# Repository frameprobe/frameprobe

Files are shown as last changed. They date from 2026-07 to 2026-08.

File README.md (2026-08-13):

# frameprobe

End-to-end display latency measurement: the time from a mouse input (click or
movement) to a visible change on screen, measured with a photodiode strapped to
the monitor.

**How it works:**

- An RP2040 sends a USB HID mouse click (or, in move mode, a mouse movement)
- The input causes a brightness change on the monitor under test (any application works, as long as the brightness difference is big enough)
- The photodiode picks up the change
- The RP2040 streams ADC samples over serial
- The host logs them to CSV
- `analyze.py` computes the latency

## Components

| Component | Path | Description |
|---|---|---|
| Hardware | `hardware/` | KiCad 10 PCB source (`hardware/pcb/`) and 3D-printable enclosure for the sensor (VBPW34S photodiode + TLV9061 transimpedance amplifier). |
| Firmware | `arduino/` | Runs on any RP2040 board. Fires the mouse input (click, or a single 16-bit HID move report in move mode), samples the photodiode on A1 (14-bit ADC, 12,000 samples per run), sends results as CSV lines over serial. |
| Host software | `main.py` | Interactive serial terminal. Starts/stops test runs, configures measurement mode, click count and interval, logs device data to `output/*.csv`. |
| Analyzer | `analyze.py` | Computes latency from session CSVs or whole folders. Reports signal/noise separation, mean ± 95% CI, sd, median, p5, p95, spread, min, max and an ASCII histogram. Every field is explained in [analyze.md](./analyze.md). |
| Chart data | `analyze_all.py` | Pools each direct subfolder of a results folder and prints chart-ready JSON (medians with error bars, plus shared-bin histograms) for comparing test cases. |
| Reference data | `test_run1/` | Captures and notes from an X11-vs-Wayland test matrix on a 500 Hz QD-OLED (`test_setup.md`, `test_matrix.md`). Done with Perfboard-era sensor, use `-t 100` to reproduce the published numbers. |

## Images

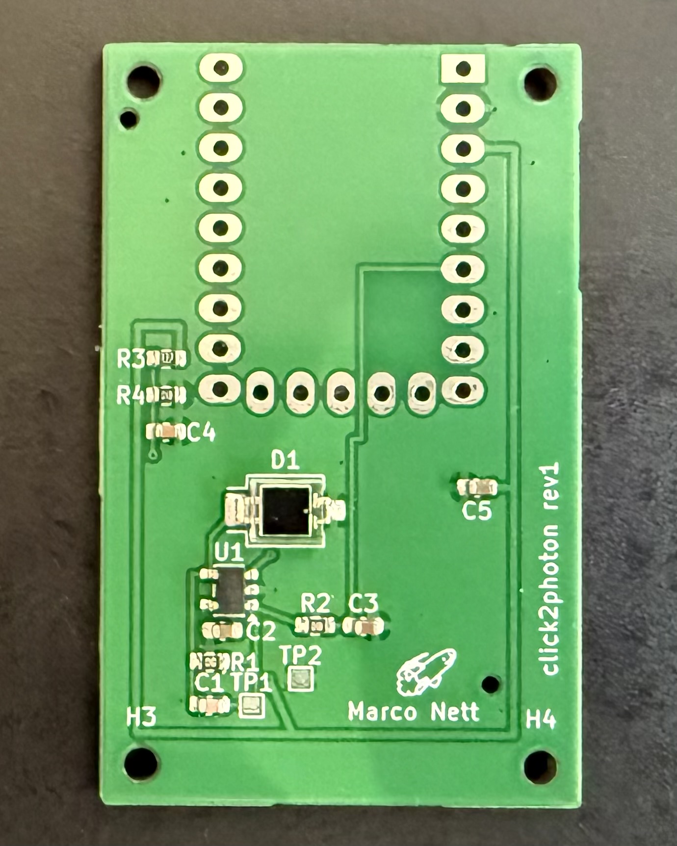
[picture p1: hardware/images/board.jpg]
Board
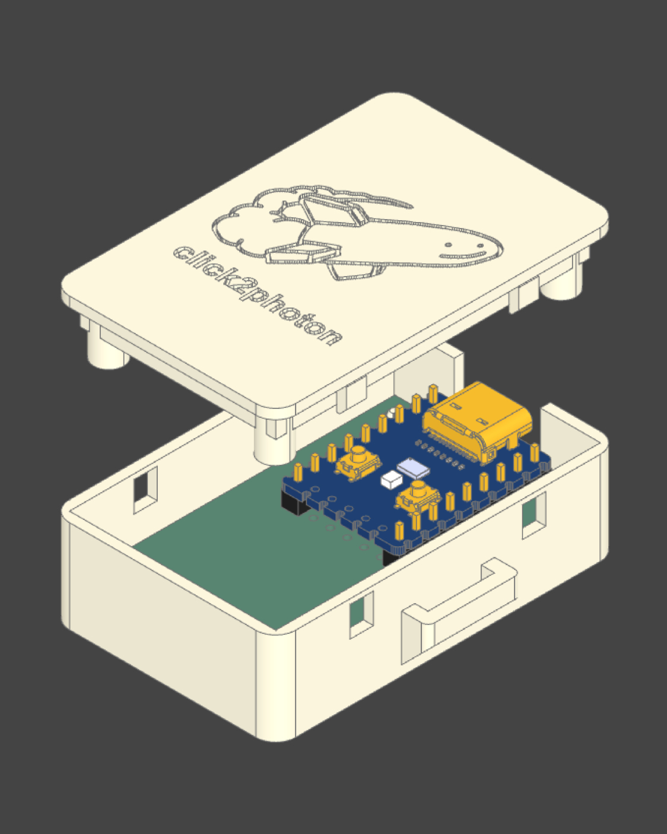
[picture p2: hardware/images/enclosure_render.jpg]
Enclosure Render
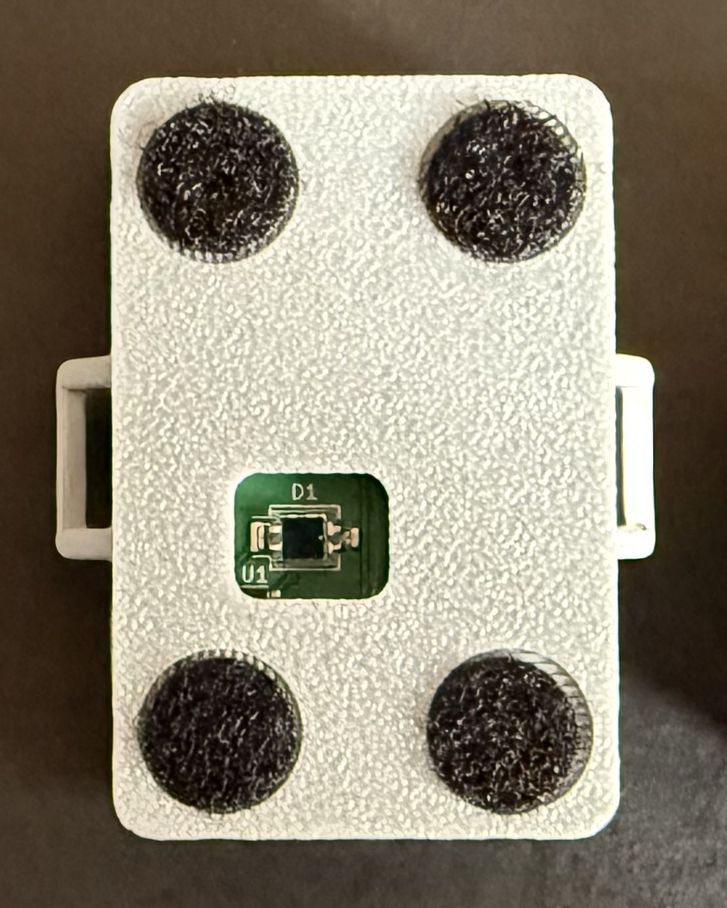
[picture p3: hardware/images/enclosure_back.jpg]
Enclosure Back
  

## Host software CLI (`main.py`)

Auto-detects the device by USB VID/PID and provides an interactive prompt. Pass a port
as the first argument to override the search (`uv run main.py /dev/ttyACM1`).

| Command | Description |
|---|---|
| `start` | Start a test session (3s countdown). Logs to `output/<timestamp>_session.csv`. |
| `stop` | Stop the test and close the session CSV. |
| `debug`, `d` | Enable debug mode: device streams raw ADC readings and voltage. |
| `interval <float>`, `i <float>` | Set the time between measurements in seconds (default 0.5). |
| `clicks <int>`, `c <int>` | Set the number of measurements per session (default 10). |
| `mode <click\|move>`, `m <...>` | Set the measurement mode (default `click`). |
| `distance <1-32767>`, `x <int>` | Move mode: distance in HID counts, sent as one atomic report (default 500). |
| `direction <up\|down\|left\|right>`, `r <...>` | Move mode: direction (default `right`). |
| `test`, `t` | Move mode: Fire one visible move with the current settings, then move back after 1s. |
| `connect` / `disconnect` | Open / close the serial connection. |
| `help` | Show the command list. |
| `exit`, `quit` | Disconnect and quit. |

## Measurement modes

- **Click** (default): each measurement is a left mouse click, e.g. a muzzle
  flash in a game, or an app that toggles the screen color on click.
- **Move**: each measurement is a single mouse movement, e.g. camera turns in
  a game. After each measurement the firmware moves the cursor back to where it started.

## Usage

`main.py` and `analyze.py` run on macOS, Linux and Windows.

Before starting a session, run an application on the PC under test in
which the mouse input causes a sufficiently large brightness change.

```sh
uv sync                     # set up Python environment
uv run main.py              # connect to the device, then type: start
uv run main.py COM5         # might be needed in Windows if COM port auto-detect fails
uv run analyze.py output/<session>.csv
uv run analyze.py output/   # or pool a whole folder of sessions
```

By default, `analyze.py` automatically calibrates based on the given input files.

## Test run

`test_run1/` contains methodology and results of the testing I did for a blog post: [Measuring input latency on Linux: X11 vs Wayland, VRR, and DXVK](https://marco-nett.de/blog/measuring-input-latency-on-linux-x11-vs-wayland-vrr-dxvk/).

This test run was done with a proof-of-concept design of the PCB with less sensitivity. To replicate the results from the blog post exactly, use the analyzer with its historical threshold of 100, for example: `uv run analyze.py test_run1/output/1_x11_ll-ON_vrr-ON -t 100`.

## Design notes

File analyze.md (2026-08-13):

# analyze.py output explained

Each value describes the click-to-photon latencies of one file or one pooled folder (all clicks from all its CSV files together).

For each click, the latency is the moment the light level crosses the midpoint (50%) of that click's own dark↔light swing and stays past it for 5 samples (timestamped at the first) — both reference levels are medians measured from the click's samples, so no per-hardware threshold tuning is needed. The same swing also yields two supplementary timestamps per click, t10 (onset) and t90 (near-settled). All headline stats come from the 50% crossing (t50). Passing `-t` instead uses the legacy fixed-delta detection (first single sample more than the given ADC delta away from the mean baseline), which reproduces the originally published numbers exactly.

- **mode** — which input event the sessions measured: *click* or *move* (read from the metadata comment line newer captures carry). Only shown when at least one file has metadata; files recorded before the metadata line existed are listed as *unknown*, so a pooled folder that mixes tagged and untagged sessions says so instead of claiming a single mode.

- **reference** — only shown with `--from-delivery`: latencies count from the moment the USB host actually picked the click report up off the device, not from the firmware pressing the button. A mouse only hands its click to the PC when the PC polls for it (every 1 ms here), so the default numbers include a random 0–1 ms wait — that's real button-to-photon latency, what a person feels. `--from-delivery` removes exactly that wait (newer captures record it per click), giving a tighter number that isolates the PC + display pipeline — better for A/B-ing displays, but ~0.5 ms lower than what a user experiences. Only captures that recorded the delivery moment can be re-referenced; older files are skipped as *no-delivery*.

- **detection** — how latencies were timed. In automatic mode it also reports the signal/noise separation: each click's swing divided by the peak-to-peak noise of its pre-click window. The minimum is the worst click in the set — if it drops toward ~2×, the sensor is barely seeing the transition (reposition it).

- **measurements** — number of clicks with a detected screen change. *skipped* = clicks with no valid transition, broken down by reason: *no-transition* (missed click, slipped sensor — swing within noise), *incomplete* (change still in progress at capture end), *malformed* (unparseable row), *no-delivery* (the host never picked the click up — device unplugged or host suspended mid-run; or, under `--from-delivery`, a file too old to record delivery); they are excluded from all stats.

- **flicker** — only shown when some clicks were measured through temporal light modulation (TLM). TLM is the umbrella term for any periodic brightness variation of the display: a PWM-strobed backlight (e.g. MacBook Pro mini-LED, ~3 kHz) and a deep OLED per-refresh brightness dip (e.g. QD-OLED at its refresh rate) look identical to the photodiode, so the analyzer names what it measures rather than guessing the cause — the reported frequency tells you which it is (kHz range → likely backlight PWM, ≈ the refresh rate → refresh flicker). Modulation that reaches past the midpoint of the swing corrupts normal crossing detection, so every click is checked before detection: when a reference window oscillates strongly periodically and the oscillation reaches past the midpoint, detection runs on a moving average of exactly one modulation period, which cancels the modulation — so those clicks are measured the same way regardless of direction. The line reports how many clicks this applied to and the modulation frequency. Timing is blurred by at most one modulation period, and the separation figures for these clicks describe the filtered signal. Mild flicker that stays below the midpoint does not trigger this and keeps raw detection.

- **delivery** — only shown for captures that record it: how long each click sat on the device before the host's USB poll picked it up (median, min, max). Expect a median around 0.5 ms spread across 0–1 ms — the physics of 1000 Hz polling. It is a diagnostic, always relative to the press regardless of `--from-delivery`: values hugging 1 ms or beyond suggest the host was polling slowly or the bus was busy. This is exactly the component `--from-delivery` subtracts.

- **mean ± … (95% CI)** — average latency. The ± is the uncertainty of that average: rerunning the same test would land the mean inside this range 95% of the time. Two cases whose ranges don't overlap are genuinely different. For folders, the margin is widened if the individual sessions disagree with each other.

- **median** — the middle click: half were faster, half slower. Like the mean but immune to a few extreme values.

- **p5** — the fast tail: 5% of clicks were faster than this. Approximates the best-case pipeline latency (click landed at the luckiest moment of the refresh cycle). A robust version of *min*.

- **p95** — the slow tail: 5% of clicks were slower than this. The "feels laggy" number — worst cases players actually notice. Where frame-pacing features should show their effect.

- **spread (p95 − p5)** — consistency: how wide the typical latency range is. Smaller = more predictable feel. More meaningful than sd, which is inflated the same way everywhere.

- **min / max** — single fastest and slowest click. Sanity checks only; each is one sample, so don't base conclusions on them.

- **onset (t10)** — median time to 10% of the swing: the earliest defensible "light started changing" moment, closest to a first-photon latency. Only counted for clicks where 10% of the swing clears the pre-click peak-to-peak noise — on a flickering white QD-OLED baseline that level is inside the flicker, so those clicks report t50 but no t10 (the report says how many). Absolute onset numbers are noise-floor dependent; use t50 for comparisons.

- **response (t10→t90)** — median time from 10% to 90% of the swing: how long the measured transition itself takes. This is sensor + panel combined — on the slow perfboard sensor it is dominated by the amplifier, on the fab PCB it approaches the panel's true response — so it is comparable within one sensor generation only.

- **histogram** — latency distribution in 0.5 ms bins; each row shows a bin's count as a bar. Shows the shape a single number can't: whether the whole block shifts between cases, whether a case has a longer tail, or whether clicks clump at multiples of the 2 ms frame period.

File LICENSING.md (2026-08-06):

# Licensing

Copyright (C) 2026 Marco Nett.

| Path | Licence |
|---|---|
| `hardware/` — PCB source, enclosure | CERN-OHL-S v2, strongly reciprocal ([`hardware/LICENSE`](hardware/LICENSE)) |
| `arduino/`, `main.py`, `analyze*.py`, `*.sh` | GPL-3.0-or-later ([`LICENSE`](LICENSE)) |

## Name and logo

**All rights to the frameprobe name and the rocket logo are reserved.**
Neither licence grants trademark or design rights. This covers the logo
wherever it appears: the PCB silkscreen and gerbers, the enclosure STLs, and
the renders and photos. Remove both before fabricating a modified board or
enclosure, and use your own branding. CERN-OHL-S counts trademark notices as
*Notices* (§1.10) and requires they be retained (§3.3), so this reservation
carries into derivatives.

## Third-party material

Not my work, not covered by the licences above, and under their authors' own
terms. Both are cosmetic, 3D preview and STEP/STL export only, not the
electrical design or the fab outputs:

- `hardware/pcb/3dmodels/RP2040-Zero.step`: Waveshare RP2040-Zero model, STEP
  header credits `xiaojisheng`
- `hardware/pcb/3dmodels/LED_VBPW34S_VIS.step`: Vishay

The design also uses KiCad's standard footprint libraries, whose CC-BY-SA-4.0
licence has an exception allowing this without the design becoming a derivative.
Build dependencies (arduino-pico, Adafruit NeoPixel, pyserial,
prompt_toolkit) are fetched, not redistributed here.

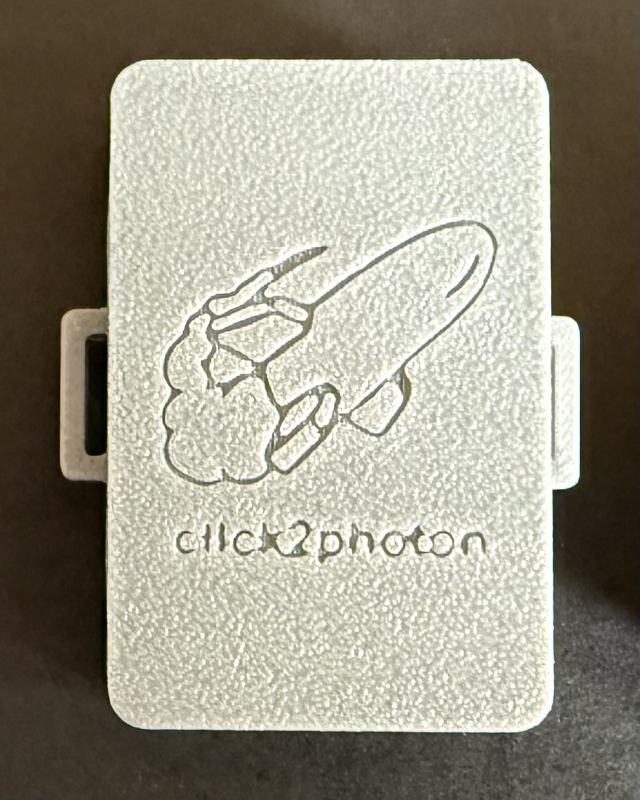
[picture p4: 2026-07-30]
hardware/images/enclosure_front.jpg

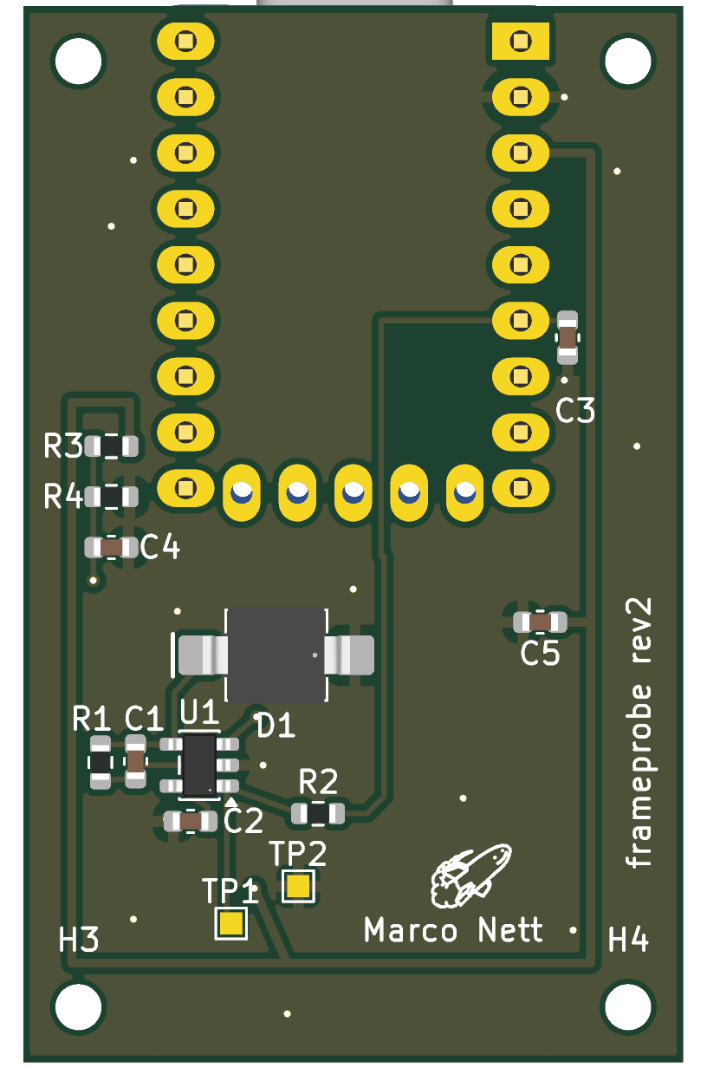
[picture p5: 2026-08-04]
hardware/pcb/render_top.png

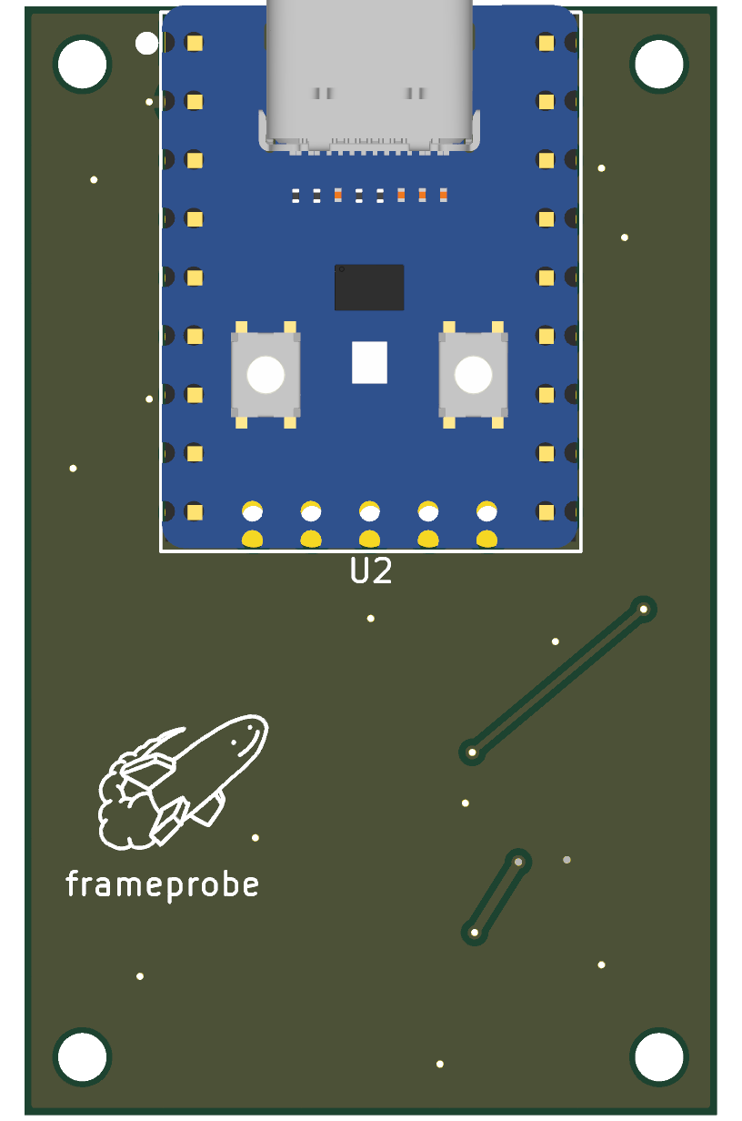
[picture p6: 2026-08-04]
hardware/pcb/render_back.png

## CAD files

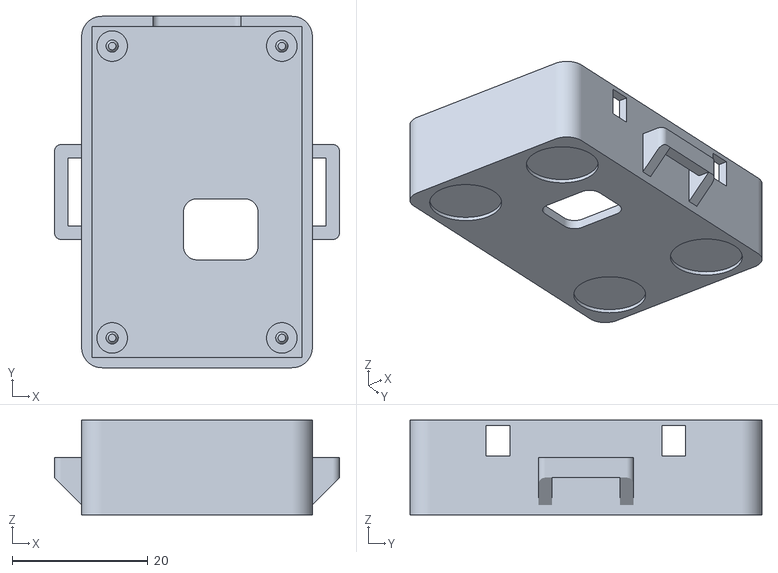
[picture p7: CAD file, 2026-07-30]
hardware/enclosure/case.stl
42.0 x 51.8 x 13.9

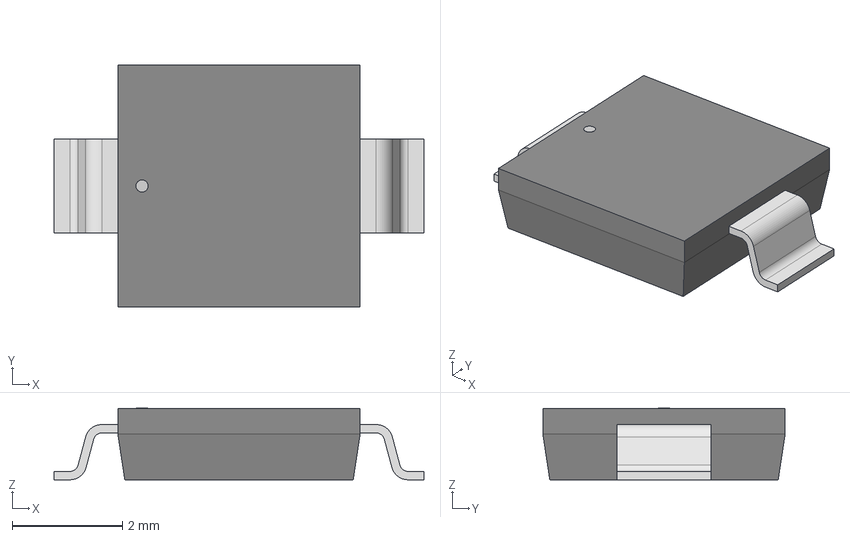
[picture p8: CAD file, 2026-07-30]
hardware/pcb/3dmodels/LED_VBPW34S_VIS.step
6.71 x 4.39 x 1.30 mm

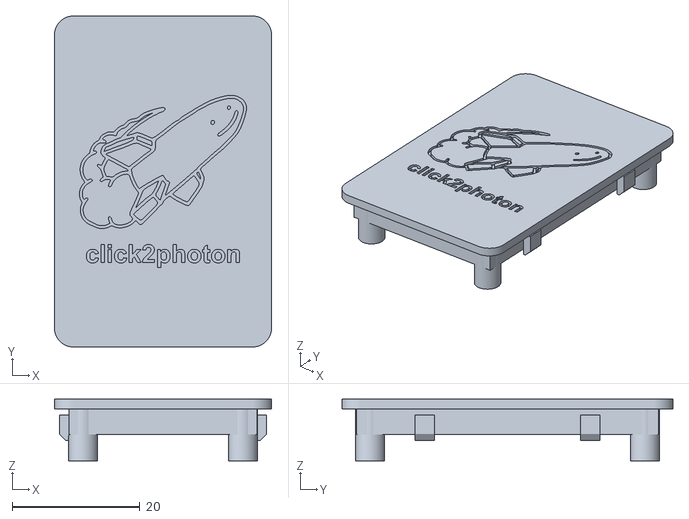
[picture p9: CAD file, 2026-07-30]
hardware/enclosure/lid.stl
34.0 x 51.8 x 9.65

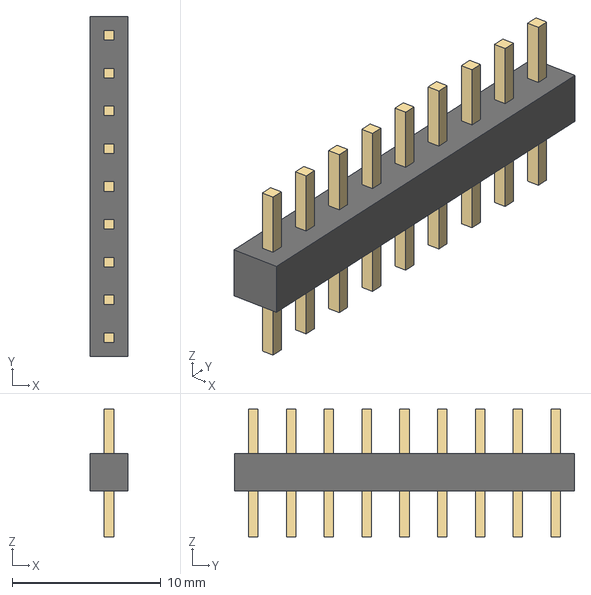
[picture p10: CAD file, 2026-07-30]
hardware/pcb/3dmodels/PinHeader_1x09_clipped.step
2.54 x 22.9 x 8.60 mm
insulator
pins

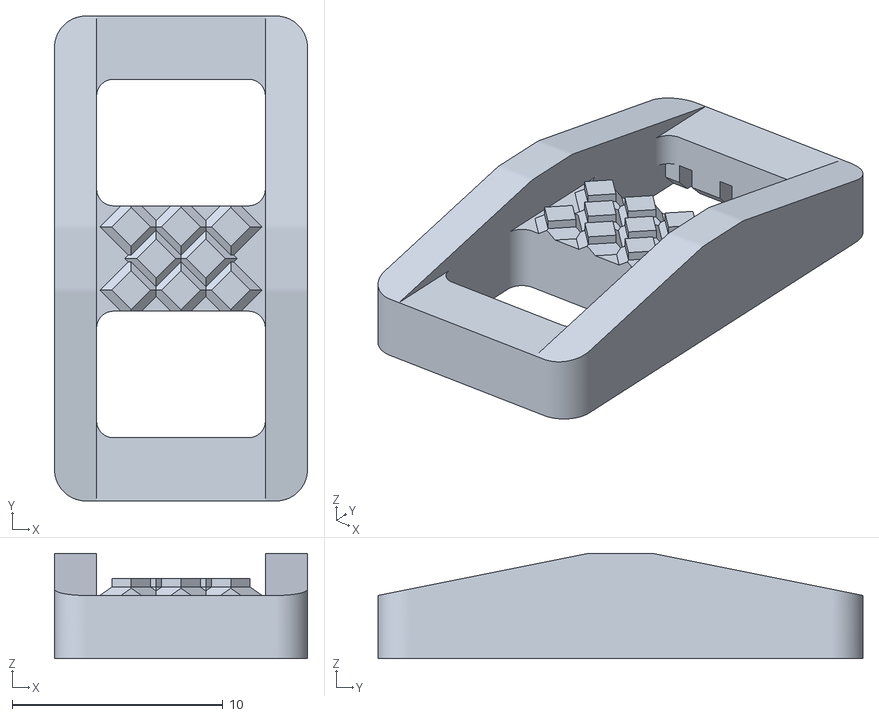
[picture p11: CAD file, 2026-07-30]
hardware/enclosure/strap_buckle.stl
12.0 x 23.0 x 5.00

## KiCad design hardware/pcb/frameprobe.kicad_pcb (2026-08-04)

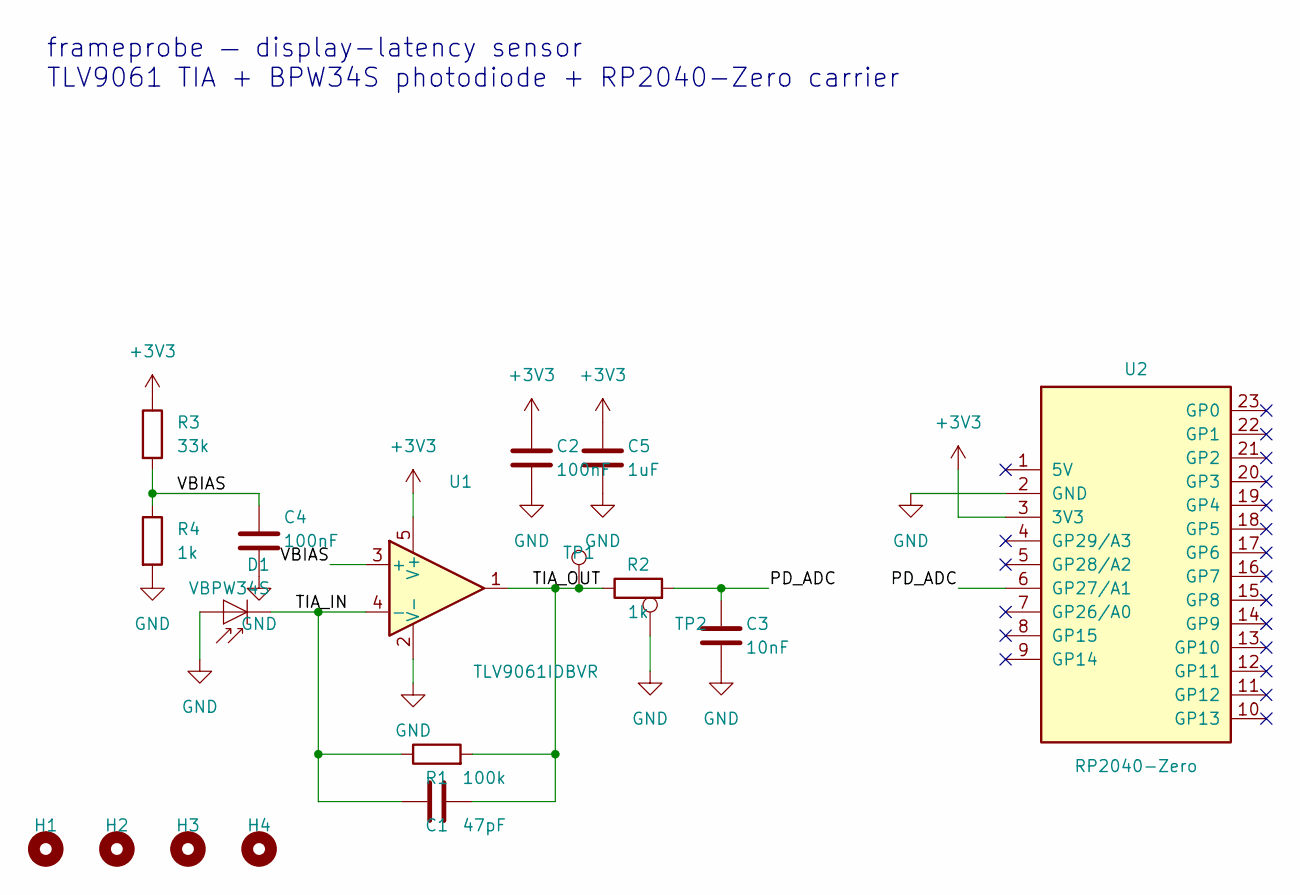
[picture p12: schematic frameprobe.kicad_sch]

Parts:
C1: 47pF; C_0603_1608Metric; LCSC C1671
C2, C4: 100nF; C_0603_1608Metric; LCSC C14663
C3: 10nF; C_0603_1608Metric; LCSC C57112
C5: 1uF; C_0603_1608Metric; LCSC C15849
D1: VBPW34S; LCSC C145262
H1, H2, H3, H4: MountingHole; MountingHole_2.1mm
R1: 100k; R_0603_1608Metric; LCSC C25803
R2, R4: 1k; R_0603_1608Metric; LCSC C21190
R3: 33k; R_0603_1608Metric; LCSC C4216
TP1: TIA_OUT; TestPoint_Pad_1.0x1.0mm
TP2: GND; TestPoint_Pad_1.0x1.0mm
U1: TLV9061IDBVR; SOT-23-5; LCSC C398358
U2: RP2040-Zero; RP2040-Zero_THT

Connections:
+3V3: C2.1, C5.1, R3.1, U1.5 (V+), U2.3 (3V3)
/PD_ADC: C3.1, R2.2, U2.6 (GP27/A1)
/TIA_IN: C1.1, D1.2 (K), R1.1, U1.4 (-)
/TIA_OUT: C1.2, R1.2, R2.1, TP1.1, U1.1
/VBIAS: C4.1, R3.2, R4.1, U1.3 (+)
GND: C2.2, C3.2, C4.2, C5.2, D1.1 (A), R4.2, TP2.1, U1.2 (V-), U2.2 (GND)

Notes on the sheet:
frameprobe — display-latency sensor TLV9061 TIA + BPW34S photodiode + RP2040-Zero carrier

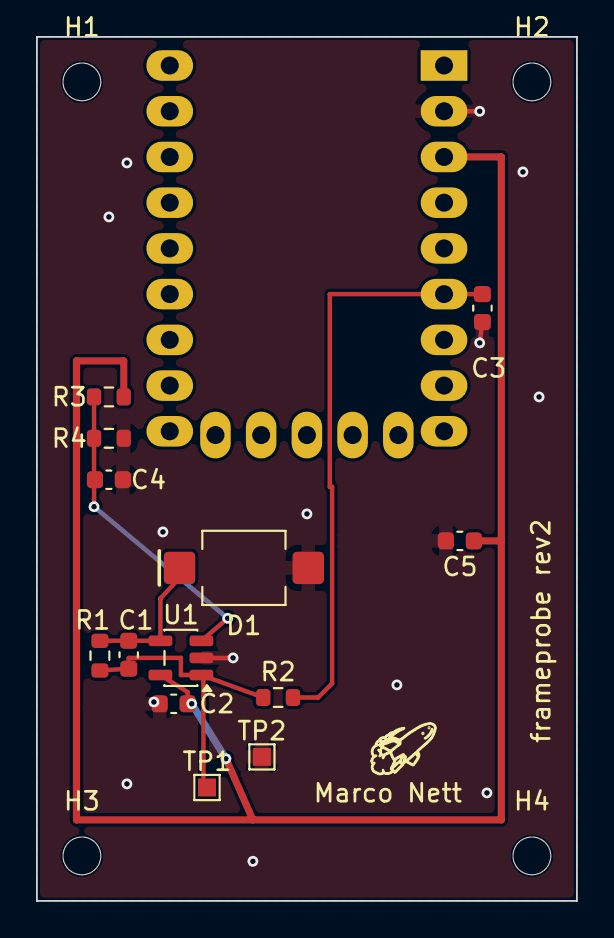
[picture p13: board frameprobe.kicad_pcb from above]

Board: 2 copper layers, 30.0 x 48.0 mm, 18 parts (1 on the bottom side), 6 nets.

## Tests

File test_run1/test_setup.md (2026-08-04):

# Test setup

## Hardware

- Mainboard: B450 GAMING PRO CARBON AC
- CPU: AMD Ryzen 7 5800X3D (16) @ 4.55 GHz
- GPU: NVIDIA GeForce RTX 4070 SUPER
- RAM: 2x8GB DDR4, 3200 MHz
- Monitor: MSI MAG 272QP QD-OLED X50 (500 Hz)
- Only one screen was connected to the system during the test

## Software

```sh
{
    echo "date: $(date -I)"
    echo "kernel: $(uname -r)"
    pacman -Q kwin
    pacman -Q xorg-server
    pacman -Q nvidia-utils
    pacman -Q proton-cachyos
    scxctl get
  } | tee versions.txt
```

Output:

```
date: 2026-07-12
kernel: 7.1.3-2-cachyos
kwin 6.7.2-1.1
xorg-server 21.1.24-1.1
nvidia-utils 610.43.03-1
proton-cachyos-native 1:11.0.20260602-3
no scx scheduler running
```

The test was done based on commit `7bc3f05` of frameprobe.

## System Settings

- 500 Hz
- Flip mode:
  - X11: On (via `nvidia-settings`)
  - Wayland: confirmed to be on (see below how)
- If VRR was tested:
  - X11: Enabled via `nvidia-settings` (changing this requires a reboot)
  - Wayland: Enabled via KDE Settings Menu (no reboot needed)
- `showcompositing` was off on Wayland (see [here](https://www.reddit.com/r/linux_gaming/comments/1u1z4qf/kde_kwin_patches_aiming_to_optimize_gaming/oqvlwdb/))

Flip mode (direct scanout) vs Blit mode (compositing) on Wayland: There is setting on Wayland, it decides itself if it composits a frame or uses direct scanout.\
To make sure the game is running in flip mode: Open "Kwin Debug Console" (it's a GUI tool) and in the "Effects" tab, enable `showcompositing`. Then make sure the game is fully focused and the only thing on screen in fullscreen mode. If there's no red border visible around the edged of the game, it's on Flip mode.

### dxvk

In all cases, the following is set in `dxvk.conf`:

```conf
d3d11.cachedDynamicResources = "c"
```

Depending on the test, an optimal `dxvk.conf` was setup:
- If VRR was off, `dxgi.maxFrameRate` was capped to 500 fps (the screens refresh rate)
- If VRR was on and `PROTON_DXVK_LOWLATENCY` was off, `dxgi.maxFrameRate` was capped to 497 fps (slightly below screen refresh rate)
- If VRR was on and `PROTON_DXVK_LOWLATENCY` was on, the following was used to utilize the low latency VRR frame pacing

```conf
# see https://github.com/netborg-afps/dxvk-low-latency
dxgi.maxFrameRate = 480
dxvk.lowLatencyOffset = 70
dxvk.framePace = "low-latency-vrr-500"
dxvk.lowLatencyAllowCpuFramesOverlap = False
```

## Game Settings

Test was done in Diabotical.

Settings:

- Everything Video Setting as low as possible
- 100% Render resolution
- Native resolution (2560×1440)
- Vsync off

## Methodology

- Close unnecessary Software
- Launch game
- Start a wipeout match, Map: wo_wellspring
- Move to a specific spot, put mouse on specific landmark
- Run the test case (100 clicks, runs for about 2 minutes)
- Once the test is done, start the next test case iteration

- Ingame conditions: No bots, no other players, no movement, no round restarts. It is basically just a static scene that will stay like this indefinitely.
- System conditions: During the test run, nothing else should be running and no significant other processes run on the system.

To start the test via frameprobe:

```sh
uv run main.py
clicks 100
start
```

## Special test case: PROTON_ENABLE_WAYLAND

The setting "Enable wine-wayland" in Heroic Launcher corresponds to `PROTON_ENABLE_WAYLAND`. If not otherwise noted, all tests were done with `PROTON_ENABLE_WAYLAND=1` (native Wayland, no use of XWayland)

- `PROTON_ENABLE_WAYLAND=1` implies native Wayland
- `PROTON_ENABLE_WAYLAND=0` implies XWayland

## Setup notes

```sh
cd /home/hst/Games/Heroic/Diabotical/
cp diabotical.exe-TESTLATENCY diabotical.exe
```

In diabotical:
- `/bind mouse_left testlatency`
- Setup hud with accent box

```sh
cp diabotical.exe-ORIG diabotical.exe
```

Ingame: `/bind mouse_left attack`

## Ideas

Future test run ideas:

1. Testing different kernel schedulers:

```sh
sudo scxctl start --sched cosmos --mode gaming
sudo scxctl start --sched lavd --mode gaming
sudo scxctl stop
```

2. Compare against: https://themaister.net/blog/2026/07/02/my-side-quest-measuring-input-latency-with-vk_ext_present_timing/

3. Try different compositors (niri)

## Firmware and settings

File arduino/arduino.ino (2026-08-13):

#include <Adafruit_NeoPixel.h>
#include "mouse16.h"

#define FIRMWARE_VERSION "1.3.0"

#define NUMPIXELS 1

Adafruit_NeoPixel pixelLED(NUMPIXELS, PIN_NEOPIXEL, NEO_GRB + NEO_KHZ800);

// override arduino-pico's weak default of 10 (USB.cpp) — a 10ms HID bInterval
// adds a uniform 0-10ms host-poll delay to every measurement; 1ms matches a
// 1000Hz gaming mouse
int usb_hid_poll_interval = 1;

void setup() {
  // init serial
  Serial.begin(115200);
  while(!Serial); // wait for device to come online
  delay(2000); // Give time for USB to stabilize

  // init neopixel (NEOPIXEL_POWER only exists on boards with a switched
  // NeoPixel rail like the QT Py; the RP2040-Zero powers it directly)
#ifdef NEOPIXEL_POWER
  pinMode(NEOPIXEL_POWER, OUTPUT);
  digitalWrite(NEOPIXEL_POWER, HIGH);
#endif

  pixelLED.begin();
  pixelLED.setBrightness(20);
  pixelLED.setPixelColor(0, pixelLED.Color(255, 0, 0));
  pixelLED.show();

  analogReadResolution(14); // set ADC resolution to 14 bits (0-16383)

  // seed RNG from ADC noise — unseeded random() repeats the same sequence every
  // boot, which would make the inter-click jitter identical across sessions
  uint32_t seed = micros();
  for (int i = 0; i < 32; i++) {
    seed = (seed << 1) ^ analogRead(A1);
  }
  randomSeed(seed);

  // init mouse
  Mouse16.begin();
}

bool isRunning = false;
bool isDebugRunning = false;
float timeBetweenClicks = 0.5; // seconds
int clickCount = 10;
int currentClickCount = 0;
bool isMoveMode = false;   // false = click mode (default)
int moveDistance = 500;    // HID counts, 1-32767: always one atomic report (16-bit HID axes)
char moveDirection = 'r';  // 'u', 'd', 'l', 'r'

#define SampleCount 12000
#define PreClickSamples 2000 // ~48ms of baseline before click, enough for ADC drift to settle (~12ms)
uint16_t adcBuff[SampleCount];

// read a one-character command argument; the host sends command+arg together,
// but wait up to the serial parse timeout in case the bytes arrive split
char readCharArg() {
  unsigned long start = millis();
  while (!Serial.available() && millis() - start < 1000);
  return Serial.available() ? (char)Serial.read() : '\0';
}

const char* directionName(char d) {
  switch (d) {
    case 'u': return "up";
    case 'd': return "down";
    case 'l': return "left";
    default:  return "right";
  }
}

// map distance + direction to a HID report delta; HID Y is positive-down
void computeMove(int &dx, int &dy) {
  dx = 0;
  dy = 0;
  if (moveDirection == 'r')      dx =  moveDistance;
  else if (moveDirection == 'l') dx = -moveDistance;
  else if (moveDirection == 'u') dy = -moveDistance;
  else                           dy =  moveDistance;
}

void runTest() {
    int currentSampleCount = 0;
    unsigned long startTimer = micros();

    // Phase 1: collect pre-click baseline samples (ADC drift settles within ~12ms)
    while (currentSampleCount < PreClickSamples) {
      adcBuff[currentSampleCount] = analogRead(A1);
      currentSampleCount++;
      delayMicroseconds(20);
    }

    // Phase 2: fire the input event (click or move, depending on mode);
    // dx/dy computed up front so the mapping cost never lands in clickDuration
    int dx, dy;
    computeMove(dx, dy);
    unsigned long clickTime = micros();
    if (isMoveMode) Mouse16.move(dx, dy);
    else Mouse16.press(MOUSE_LEFT);
    unsigned long afterClick = micros();
    unsigned long clickDuration = afterClick - clickTime;

    // Phase 2b: wait until the host's 1ms poll actually picked the report up,
    // so deliveryTime pins the moment the input reached the host (press only
    // queues the report; pickup is 0-1ms later). The wait sits between the
    // sampling phases instead of inside phase 3 because analyze.py timestamps
    // by index x average sample period — pumping tud_task() inside the
    // sampling loop would make early post-click samples slower than that
    // average and skew every crossing after them. Up to ~1ms without samples
    // right after the press is harmless: the report hasn't even reached the
    // host yet, so the screen cannot have changed. deliveryTime = 0 means
    // never delivered (host stopped polling); analyze.py drops such rows
    unsigned long deliveryTime = 0;
    if (Mouse16.waitDelivered()) {
      deliveryTime = micros() - clickTime;
    }

    // Phase 3: collect post-click samples capturing the transition
    while (currentSampleCount < SampleCount) {
      adcBuff[currentSampleCount] = analogRead(A1);
      currentSampleCount++;
      delayMicroseconds(20);
    }

    unsigned long endTimer = micros();
    unsigned long timeTaken = endTimer - startTimer;

    if (!isMoveMode) Mouse16.release(MOUSE_LEFT);

    Serial.print("CSV");
    Serial.print(clickDuration);
    Serial.print(",");
    Serial.print(timeTaken);
    Serial.print(",");
    Serial.print(SampleCount);
    Serial.print(",");
    Serial.print(PreClickSamples); // click sample index so host knows where the click happened
    Serial.print(",");

    for (int i = 0; i < SampleCount; i++) {
      Serial.print(adcBuff[i]);
      Serial.print(";");
    }

    // appended after samples, not inserted mid-row: an old main.py writes new
    // rows under its 5-name header, and a trailing extra field is ignored by
    // DictReader while an inserted one would shift every column silently
    Serial.print(",");
    Serial.print(deliveryTime);
    Serial.println();
    Serial.flush(); // wait for serial data to fully transmit before next measurement — HID and CDC share the USB bus, so lingering serial traffic can delay Mouse16.press() delivery

    if (isMoveMode) {
      // return the cursor to its starting position
      Mouse16.move(-dx, -dy);
    }
}

void loop() {
  if (Serial.available()) {
    char cmd = Serial.read();

    if (cmd == '1') {
      pixelLED.setBrightness(0);
      pixelLED.show();

      // machine-readable session settings: main.py copies the payload into the
      // session CSV as a comment line; hosts that don't know META print it as
      // plain status output
      Serial.print("META,mode=");
      Serial.print(isMoveMode ? "move" : "click");
      if (isMoveMode) {
        Serial.print(",distance=");
        Serial.print(moveDistance);
        Serial.print(",direction=");
        Serial.print(directionName(moveDirection));
      }
      Serial.println(",firmware=" FIRMWARE_VERSION);

      Serial.println("Starting latency test in 3 seconds...");
      Serial.println("Mode: " + String(isMoveMode ? "move" : "click"));
      if (isMoveMode) {
        Serial.println("Move distance: " + String(moveDistance) + " counts, direction: " + String(directionName(moveDirection)));
      }
      Serial.println("Current time between clicks: " + String(timeBetweenClicks) + " seconds");
      Serial.println("Current click count: " + String(clickCount));

      delay(3000);
      isRunning = true;
    } else if (cmd == '0') {
      isRunning = false;
      isDebugRunning = false;
      currentClickCount = 0;

      Serial.println("Stopped");
      pixelLED.setBrightness(20);
      pixelLED.setPixelColor(0, pixelLED.Color(255, 0, 0));
      pixelLED.show();
    } else if (cmd == 'd') {
      pixelLED.setBrightness(0);
      pixelLED.show();

      Serial.println("Enabled debug mode");
      isDebugRunning = true;
    } else if (cmd == 'i') {
      float newInterval = Serial.parseFloat();
      if (newInterval > 0) {
        timeBetweenClicks = newInterval;
        Serial.println("Interval set to: " + String(timeBetweenClicks) + " seconds");
      } else {
        Serial.println("Invalid interval value");
      }
    } else if (cmd == 'c') {
      long newClickCount = Serial.parseInt();
      if (newClickCount > 0) {
        clickCount = newClickCount;
        Serial.println("click count set to: " + String(clickCount));
      } else {
        Serial.println("Invalid click count value");
      }
    } else if (cmd == 'm') {
      char mode = readCharArg();
      if (mode == 'c' || mode == 'm') {
        isMoveMode = (mode == 'm');
        Serial.println("Mode set to: " + String(isMoveMode ? "move" : "click"));
      } else {
        Serial.println("Invalid mode (mc = click, mm = move)");
      }
    } else if (cmd == 'x') {
      long newDistance = Serial.parseInt();
      if (newDistance >= 1 && newDistance <= 32767) {
        moveDistance = newDistance;
        Serial.println("Move distance set to: " + String(moveDistance) + " counts");
      } else {
        Serial.println("Invalid move distance (1-32767)");
      }
    } else if (cmd == 'r') {
      char dir = readCharArg();
      if (dir == 'u' || dir == 'd' || dir == 'l' || dir == 'r') {
        moveDirection = dir;
        Serial.println("Move direction set to: " + String(directionName(moveDirection)));
      } else {
        Serial.println("Invalid direction (u/d/l/r)");
      }
    } else if (cmd == 't') {
      int dx, dy;
      computeMove(dx, dy);
      Serial.println("Move test: " + String(moveDistance) + " counts " + String(directionName(moveDirection)) + " (resets in 1s)");
      Mouse16.move(dx, dy);
      delay(1000);
      Mouse16.move(-dx, -dy);
    } else if (cmd == 'v') {
      Serial.println("FRAMEPROBE," FIRMWARE_VERSION);
    }
  }

  // unsigned long PERF_start = micros();
  // unsigned long PERF_stop = micros();
  // Serial.print("PERF,");
  // Serial.println(PERF_stop - PERF_start);

  if (isRunning) {
    if (currentClickCount < clickCount) {
      // Serial.println("Click " + String(currentClickCount+1) + " of " + String(clickCount));
      runTest();

      // ±10ms random jitter decorrelates click timing from the display refresh
      // phase — a fixed interval can repeatedly land at the same scanout
      // position. Generated in µs, not ms: whole-ms offsets modulo a 2ms frame
      // period (500Hz) hit only two phases; µs resolution covers all of them.
      long delayUs = (long)(timeBetweenClicks * 1000000.0f) + random(-10000, 10001);
      if (delayUs < 0) delayUs = 0;
      delay(delayUs / 1000);
      delayMicroseconds(delayUs % 1000);
      currentClickCount++;
    } else {
      isRunning = false;
      currentClickCount = 0;
      pixelLED.setBrightness(20);
      pixelLED.setPixelColor(0, pixelLED.Color(255, 0, 0));
      pixelLED.show();

      Serial.println("DONE");
      Serial.flush();
      return;
    }
  }

  if (isDebugRunning) {
    uint16_t raw = analogRead(A1); // 14-bit ADC: 0 - 16383
    float voltage = (raw * 3.3) / 16383.0; // Convert to voltage
    Serial.print("Raw ADC: ");
    Serial.print(raw);
    Serial.print(", Voltage: ");
    Serial.println(voltage, 4);
  }
}

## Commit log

2026-07-30 Rework the project around the v2 sensor PCB
    The perfboard prototype (BPW34 + TLC271IP on an Adafruit QT Py) is
    replaced by a fabricated 30x48 mm board: VBPW34S photodiode into a
    TLV9061 transimpedance amplifier on the front, solder-on Waveshare
    RP2040-Zero on the back so the sensor face sits ~1 mm flat against the
    screen. The TIA output stays on GP27 = A1, so analogRead(A1) is
    unchanged from the perfboard build. export_fab.sh regenerates the
    gerbers, BOM, CPL, STEP/STL and renders, and aborts on any ERC or DRC
    violation so the fab outputs never drift from the source.
    The new sensor is much more sensitive: it swings ~565 to ~3400 ADC
    counts where the perfboard managed ~390 in total, enough t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
    [LED_VBPW34S_VIS.step, PinHeader_1x09_clipped.step, Untitled.kicad_pcb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]
2026-07-30 Make color switcher fullscreen, add latency report
    A windowed surface defeats the IMMEDIATE present mode: Wayland only
    grants tearing to fullscreen surfaces and X11 compositors only
    unredirect fullscreen windows, so presents were silently composited
    and vsync-aligned. Go fullscreen on the primary monitor at the
    desktop video mode (no mode switch), hide the cursor so it cannot
    sit over the photodiode, and disable GLFW_AUTO_ICONIFY so focusing
    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
2026-07-30 Apply latency review fixes to color switcher
    Address the actionable findings from LATENCY_REVIEW.md:
    - Allocate one render-finished semaphore per swapchain image and
    select it by the acquired image index. The in-flight fence only
    proves the graphics submit finished, not that the previous present
    consumed the semaphore (VUID-vkQueueSubmit-pSignalSemaphores-00067).
    - Re-poll events after the blocking fence wait, right before picking
    the command buffer. A click arriving during the wait was previously
    submitted one frame late.
    - Add a strict --present-mode flag that errors out when the requested
    mode is unsupported instead of silently falling back to a vsynced
    mode, and print all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
2026-07-30 Address follow-up latency review comments
    - Present only on change in FIFO/FIFO_RELAXED: the graphics fence
    does not bound presentation depth, so continuous rendering can
    queue unchanged frames that a clicked frame then waits behind,
    adding whole refresh periods in vsynced and VRR runs. IMMEDIATE
    and MAILBOX keep rendering continuously to hold GPU clocks up; a
    redundant clear ahead of the click frame costs microseconds there.
    - Revert the discrete-GPU preference to first-suitable: on hybrid
    laptops the integrated GPU often drives the panel and picking the
    discrete one would add a PRIME copy. The chosen device name is
    still printed so each run records what it used.
    - Document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
2026-07-31 Add --windowed flag to color switcher
    Run in an 800x600 window instead of fullscreen, reusing the existing
    no-monitor fallback path in initWindow(). Intended for development
    only: windowed surfaces are always composited/vsynced, so measurement
    runs should stay fullscreen.
    run_vulkan.sh now forwards its arguments to the binary so flags can
    be passed through it.
2026-07-31 Detect latency through backlight-PWM strobe
    Backlight-PWM displays (e.g. MacBook Pro mini-LED, ~3 kHz at any
    brightness) turn the lit screen into a full-scale square wave to the
    photodiode. That corrupts crossing detection in both directions:
    lit-baseline rows are skipped as no-transition because the strobe swamps
    the noise window, and black-baseline rows either never sustain a t50
    crossing through the off-phases or timestamp the first on-pulse instead
    of the averaged-luminance midpoint.
    Check every row before detection: when the noisier reference window
    oscillates past the midpoint of the raw swing (cheap peak-to-peak gate,
    so clean rows pay ~nothing) and is strongly periodic (overlap-unbi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
2026-08-04 rename to frameprobe
    [frameprobe.kicad_pcb, frameprobe.kicad_sch]
2026-08-06 moved color-switcher into dedicated repo
2026-08-06 Add mouse-move-to-photon measurement mode
    Alongside click-to-photon, the firmware can now fire a mouse movement
    as the measured input event, for latency testing against motion-
    reactive targets (e.g. a game turning the camera). Modeled on OSLTT:
    a single move report before the capture window, and the inverse move
    after the CSV dump restores the cursor so runs do not drift.
    The stock Mouse library caps relative deltas at +/-127 per report;
    chaining reports would smear the input edge across multiple 1ms USB
    polls. Instead, mouse16.h/.cpp replace it with an HID device whose
    descriptor declares 16-bit relative X/Y axes like real gaming mice,
    so any distance from 1 to 32767 counts stays one atom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
    [arduino.ino]
2026-08-08 Fix HID link failure on arduino-pico 5.5.0 and newer
    arduino-pico 5.5.0 removed the TinyUSB HID class driver from the
    prebuilt libpico.a, leaving only weak no-op stubs in the core; the real
    driver now ships as a dummy tusb-hid library that a sketch pulls into
    the build by including <tusb-hid.h>. The stock Mouse library does this
    itself, but move mode replaced it with mouse16.cpp, so nothing dragged
    the driver into the link and the build died with undefined
    tud_hid_n_report and tud_hid_n_ready. Only newer cores were affected,
    which is why the same tree built fine against 5.4.2.
    The include is guarded on ARDUINO_PICO_MAJOR/MINOR rather than
    __has_include: arduino-cli discovers libraries from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
2026-08-13 Record session mode as CSV metadata line
    Click-mode and move-mode captures were indistinguishable once saved,
    which matters as soon as both modes are compared against each other.
    The firmware now emits a machine-readable META serial line on session
    start (mode, distance/direction in move mode, firmware version) that
    main.py copies into the session CSV as a "#" comment line between the
    header and the first data row. analyze.py skips comment lines when
    parsing, and reports the mode when present; pooled folders that mix
    tagged and untagged files list "unknown" instead of claiming a single
    mode.
    Everything stays backwards compatible: old firmware sends no META, so
    its files are unchanged; host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
    [arduino.ino]
2026-08-13 Measure USB delivery of the input event per row
    Mouse16.press()/move() only queues the HID report; the host picks it
    up at its next 1ms poll, so every measurement carried an invisible
    uniform 0-1ms wait baked into the sample positions.
    The firmware now busy-waits after firing the input event until
    tud_hid_ready() flips back (the host IN token consumed the report),
    pumping tud_task() under USB.mutex — the mutex is the core tud_task()
    reentrancy guard: its 1ms IRQ pump try-enters and defers while user
    code owns it, so pumping without it could nest a tud_task() inside
    ours. The wait sits between the sampling phases, never inside them,
    because analyze.py timestamps by index times the average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
    [arduino.ino]
2026-08-13 Rename PWM flicker terminology to TLM
    The flicker gate does not observe pulse-width modulation; it detects a
    periodic brightness oscillation reaching past the swing midpoint and
    comb-filters it. Backlight PWM is only one cause: captures from a
    QD-OLED AW2725DF at 360Hz tripped the same gate on the panel per-refresh
    brightness dip, and OLEDs have no backlight, so "backlight PWM" in the
    report misattributed the cause. Temporal light modulation (TLM) is the
    display-metrology umbrella term covering both, naming what is actually
    measured.
    The report line now leads with the measured frequency so the reader can
    attribute the cause (kHz range: backlight PWM; refresh rate: OLED
    refresh flicker). Als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
2026-10-29 pcb text
